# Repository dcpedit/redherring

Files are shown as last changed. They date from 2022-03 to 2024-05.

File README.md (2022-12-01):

# Red Herring Keyboard

Red Herring is a 75% ortholinear keyboard with staggered columns and a split ergonomic layout similar to an Arisu/Alice.  Here you will find the KiCad 6 files for the PCB and plate, along with Illustrator files for the case and wrist rest. Keyboard features:
- Through-hole or hotswap socket variants
- Diodes arranged in a unique herringbone pattern
- Large rotary encoder knob (up to 48mm diameter)
- 64x128 OLED display (SSD1107)
- Compatible with most standard keycap sets (1.75u for left shift, and 2u for left space)
- Different [layout options](http://www.keyboard-layout-editor.com/#/gists/cf2afd92ae2ac742f6cb94146715b537), including ISO

## Firmware ([Vial](https://get.vial.today/)):

If you're flashing a brand new MCU, you will need to use an ISP programmer to install a bootloader first. I didn't have an AVR ISP programmer, so I flashed a spare Elite-C to do this.

Look in the `firmware` folder for hex files and more info on flashing.

## Photos:
Red Herring Keyboard - Black top
Red Herring Keyboard - OLED
Red Herring Keyboard - Black bottom
Red Herring - white case and wrist resttop
Red Herring - white case side

## Thanks!
This project would not have been possible without the time and dedication of everyone who worked on the amazing keyboards I learned and took inspiration from.  To name a few: Jabberwocky, Boardrun, Basketweave, Adelheid, Mercutio, Discipline, and Mysterium.

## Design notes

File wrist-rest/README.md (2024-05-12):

# Red Herring Wrist Rest

wrist-rest-wires

This design uses 6 layers cut out of 3mm thick acrylic.  Actual thickness may vary (mine was around 2.8mm).

## Standoffs
This build will require round M2 standoffs with the following lengths:

| |Size|Qty|
|:--|:--:|:--:|
|**Top Row**|M2x10mm|5|
|**Bottom Row**|M2x5mm|5|

## Screws
The following screw sizes are also needed
| |Size|Qty|
|:--|:--:|:--:|
|**Top Layer**|M2x8mm|10|
|**Bottom Layer (upper)**|M2x6mm|5|
|**Bottom Layer (lower)**|M2x5mm|5|

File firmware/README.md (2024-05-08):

# Red Herring Firmware

If you're flashing a brand new MCU, you need to first assemble the PCB, and then flash the ATmega32A with the USBaspLoader bootloader.

[QMK's ISP flashing guide](https://github.com/qmk/qmk_firmware/blob/master/docs/isp_flashing_guide.md)

## Flash Bootloader for the ATMEGA32A

You will need an ISP programmer to flash the Atmega32a chip with the USBaspLoader bootloader, so please refer to the QMK guide on what to use.  I had a spare Elite-C lying around, so I converted that to an ISP programmer using `pro_micro_ISP_B6_10.hex`, which was taken from the QMK guide.  Here's a pic of my makeshift setup.  (I put a small amount of solder on the wire pins and tacked them down onto the pads so that I could easily remove them later)



Wire your ISP programmer up to the PCB header using the diagram below. Then connect your computer to the ISP programmer. The PCB should NOT be connected directly to your computer.

redherring-isp-pins

Install `avrdude` or QMK MSYS for Windows:
- [MacOS avrdude](https://formulae.brew.sh/formula/avrdude)
- [Windows QMK MSYS](https://msys.qmk.fm/)

Use the `bootloader.hex` and flash with the following commands.  You will need to replace `<PORT>` with the location of your ISP's USB port.  You can look in your Device Manager (Windows ex: Ports -> `COM3`), or your `/dev` directory for `tty.usb*` (MacOS ex: `/dev/tty.usbmodem12345`).  You may need to change `avrisp` to the programmer that you're using.  Again, please check the [QMK docs](https://github.com/qmk/qmk_firmware/blob/master/docs/isp_flashing_guide.md) for more info.

### View attached device
```
avrdude -c avrisp -P <PORT> -b 19200 -p atmega32 -v
```

Example output:

avrdude-verbose

### Flash bootloader
```
avrdude -c avrisp -P <PORT> -b 19200 -p atmega32 -U flash:w:bootloader.hex:i
```

Example output:

avrdude-flash

### Set fuses
```
avrdude -c avrisp -P <PORT> -p atmega32 -U lfuse:w:0x1f:m -U hfuse:w:0xc0:m
```

Example output:

avrdude-fuse

You can now disconnect your ISP programmer and connect the PCB directly to your computer via the USB-C port.  Make sure you have [QMK Toolbox](https://github.com/qmk/qmk_toolbox/releases) open so that you can monitor the status window and flash the firmware.  In order to put the board into bootloader mode you must first hold the boot button (labeled BOOT) and while holding the boot button, press the reset button (labeled RESET) and release it. Wait for another second, then release the boot button as well. The microcontroller will now be in bootloader mode if the bootloader is present and prepared correctly.

The QMK Toolbox status window should output: `USBAsp device connected`.

Continue to flash as you normally would from this point (ie. QMK Toolbox using `redherring_vial.hex`). If you have autoflash enabled on QMK Toolbox, it will do it automatically now. Reset the board once more in order to use the new firmware (you can do this by unplugging and replugging it or by pressing and releasing the reset button.)

If you're still having issues with the bootloader, you can also take a look at this detailed guide written by Protieus: [Atmega32a_Flash_Guide.pdf](https://github.com/dcpedit/redherring/blob/main/firmware/Atmega32a_Flash_Guide.pdf)

## VIA Firmware (recommended)

Source:

https://github.com/qmk/qmk_firmware/tree/master/keyboards/dcpedit/redherring

Flash the `redherring_via.hex` file and visit https://usevia.app/ to remap your keys

## Vial Firmware

You'll need the [Vial software](https://get.vial.today) if you want to remap your keys.

Source:

https://github.com/dcpedit/vial-qmk-dev/blob/dcpedit/keyboards/dcpedit/redherring

Use the `redherring_vial.hex` firmware.  Below is a list of commands to build.

```
git clone --recurse-submodules -b dcpedit https://github.com/dcpedit/vial-qmk.git
cd vial-qmk
make git-submodule
make dcpedit/redherring:vial
```

## Change OLED graphic

In order to change the image, you'll first need to create a 64x128 two-tone image using only black and white pixels (no gray) and save it as a PNG.  Once you do that, upload your image to this online image2cpp tool (https://javl.github.io/image2cpp/), and use the below settings.  Note that the output format is "plain bytes" and draw mode is "vertical - 1 bit per pixel"

image2cpp

Clicking the "Generate code" button will produce the code you need.

Next open the `redherring.c` file in `keyboards/dcpedit/redherring/`

Add a define for you image size at the top (assuming 64x128):

```
#define LOGO_SIZE 1024
```

Next define a `render_logo` function.  If one already exists, you can replace that.  This is where you paste in the code generated from image2cpp.  Here's an example of what the function would look like:

```
static void render_logo(void) {
    static const char PROGMEM oled_logo[LOGO_SIZE] = {
        /* Paste the output from image2cpp below */
        0x00, 0x00, 0x00, 0x00, 0x00, 0x00, 0x00, 0x00, 0x00, 0x00, 0x00, 0x00, 0x00, 0x00, 0x00, 0x00,
        0x00, 0x00, 0x00, 0x00, 0x00, 0x00, 0x00, 0x00, 0x00, 0x00, 0x00, 0x00, 0x00, 0x00, 0x00, 0x00,
        0x00, 0x00, 0x00, 0x00, 0x00, 0x00, 0x00, 0x00, 0x00, 0x00, 0x00, 0x00, 0x00, 0x00, 0x00, 0x00,
        /* ... should be 64 lines of this ... */
    };

    oled_write_raw_P(oled_logo, LOGO_SIZE);
}
```

Finally, update your `oled_task_kb` function in `redherring.c` to display the logo.  It should look something like this:

```
bool oled_task_kb(void) {
    if (!oled_task_user()) {
        return false;
    }
    render_logo();
    return true;
}
```

You can see an example image in the [example_logo folder](example_logo)

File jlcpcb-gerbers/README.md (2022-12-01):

# Gerber files for JLCPCB

| File | Description | Thickness | Size
| ---- | --- | --- | ----
| `pcb-gerbers.zip`  | Red Herring Through-Hole PCB | 1.6 mm | 364.4 x 167.2 mm
| `pcb-hotswap-gerbers.zip`  | Red Herring Hotswap PCB | 1.6 mm | 364.4 x 167.2 mm
| `solenoid-gerbers.zip` | Red Herring solenoid edition PCB | 1.6 mm | 364.4 x 167.2 mm
| `plate-gerbers.zip` | Red Herring switch plate (1.2mm) | 1.2 mm | 364.4 x 144.6 mm

I've pre-generated these files so that they can be uploaded directly to [JLCPCB](https://jlcpcb.com).  The were generated following [this guide](https://support.jlcpcb.com/article/149-how-to-generate-gerber-and-drill-files-in-kicad) which was written for KiCad 5.  If the website is not able to calculate the dimensions, you can enter them in manually.

For KiCad 6, I used the following settings in case anyone wanted to generate the files themselves

## Plot
KiCad6_Plot

## Generate drill files
KiCad6_Drill

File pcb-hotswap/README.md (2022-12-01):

# Red Herring PCB
#### Hotswap variant by [ungodly.design](https://ungodly.design)
The files here were created with KiCad 6.

KiCad-screenshot

## Manufacturing
I used JLCPCB.com to get this manufactured.  They have [a good tutorial](https://support.jlcpcb.com/article/149-how-to-generate-gerber-and-drill-files-in-kicad) on how to generate the Gerber files from KiCad. If the website is not able to calculate the dimensions, you can enter it in manually.  Here are the details

- Size: 364.4 mm x 167.2 mm
- Thickness: 1.6 mm FR4
- 2 Layers

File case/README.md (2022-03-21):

# Red Herring Stacked Acrylic Case and Foam

case-wires

See the [build guide](/build-guide) for the hardware information and assembly instructions.

The normal case file contains the design for a flat edge case, while the rounded file is the design for rounded edges.  (I've only built the rounded version)

There are a total of 11 layers of 3mm thick acrylic including the feet.  For the top layers that have clear windows, the windows are held in place by friction, so sizing might be a bit tricky.  I also used the natural tappering of the arcylic edges to "lock" the windows in place. It might be possible to use few dabs of acrylic cement (ie. Weld-On #4) to hold it in place, but I have not tried this.

## Acrylic Layer Descriptions

The layers should be cut out of 3mm thick acrylic.  The actual thickness of the acrylic I used was about 2.8mm.

| Layer | Description |
| ----- | --- |
| 11d Top Clear Solenoid | Clear top for solenoid edition
| 11c Top Solenoid Windows | Windows solenoid edition
| 11b Top Alternate Windows | Windows for alternate top
| 11b Top Alternate | Alternate top with windows
| 11 Top Clear | Standard clear top
| 10 Top Layer | Layer #10
| 9 Top Layer | Layer #9
| 8 Layer PCB Top | Layer that goes right above the PCB
| 7 Bottom Spacer | Layer #7
| 6 Bottom Spacer | Layer #6
| 5 Bottom | Keyboard bottom
| Feet 4 | Layer #4 (largest foot layer)
| Feet 3 | Layer #3
| Feet 2 | Layer #2
| Feet 1 | Layer #1 (smallest foot layer)

You do not need to cut all the #11 layers.  What you need will depend on which case you're building.  Follow this guide below.

### Case: clear top
- 11 Top Clear

### Case: matching color top with clear windows
- 11b Top Alternate
- 11b Top Alternate Windows

### Case - Solenoid edition: clear top
- 11d Top Clear Solenoid

### Case - Solenoid edition: matching color top with clear windows 
- 11b Top Alternate
- 11c Top Solenoid Windows

**Notes:** I had to cut a small hole in the window for the solenoid because it was too tall to fit inside the case without it.  The windows are secured in place by friction only, so the sizing is important.  I adjusted the kerf for my laser cutter, so your mileage may vary.  If the fitment is too loose, it may just fall out, but I think a few dabs of acrylic cement around the perimeter of the window may hold it in place.  If you're unsure about the window fitment, I'd suggest going with the all-clear top to be safe.

There's also a spacer file which I used to cut a ~0.5mm spacer to go in between the PCB and solenoid (for the solenoid edition).  This was helpful for a few reasons: it dapens the sounds, it allows me to use the screws I had, which would've been too long otherwise, and it prevents the solenoid piston from hitting the boot button.  The spacer doesn't have to be exact. I cut mine out of a cracker box.  Cutting one out with scissors and punching small holes for the screws will work just fine as well.

## Foam Layer Descriptions

The plate foam (between switch plate and PCB) should be 2mm thick, and the bottom foam (under the PCB) should be 1mm thick.  There's not that much room inside the case, so going too thick may cause the case the bulge.  To thin, and the PCB might shift around a bit, but probably not noticeable.  I used EVA foam, which works really well with laser cutters.

| Layer | Description |
| ----- | --- |
| Plate Foam | 2mm foam (between switch plate and PCB)
| Bottom Foam A | 1mm foam (underneath PCB)

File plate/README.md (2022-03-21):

red herring plate

# Red Herring switch plate
The files here were created with KiCad 6.

## Manufacturing
I used JLCPCB.com to get this manufactured.  They have [a good tutorial](https://support.jlcpcb.com/article/149-how-to-generate-gerber-and-drill-files-in-kicad) on how to generate the Gerber files from KiCad. If the website is not able to calculate the dimensions, you can enter it in manually.  Here are the details

- Size: 144.5 mm x 364.4 mm
- Thickness: 1.2 mm FR4 (I found that going under 1.5 mm made it easier for the switches to snap in)

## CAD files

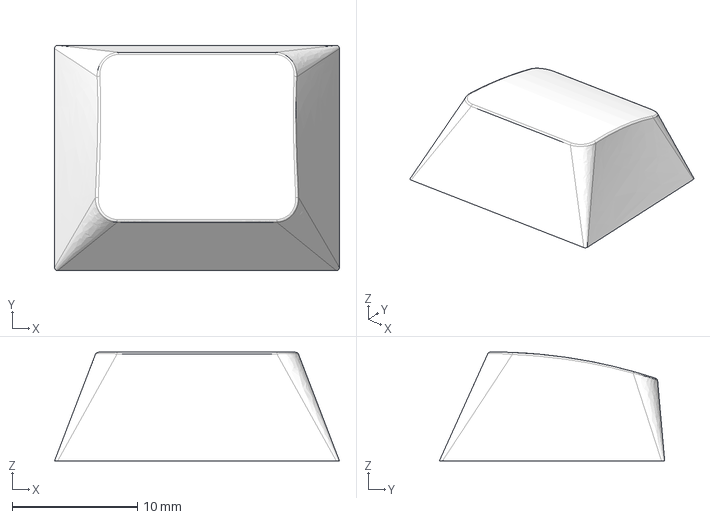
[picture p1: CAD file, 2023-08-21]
pcb-hotswap/1.25u.step
22.8 x 18.0 x 8.70 mm

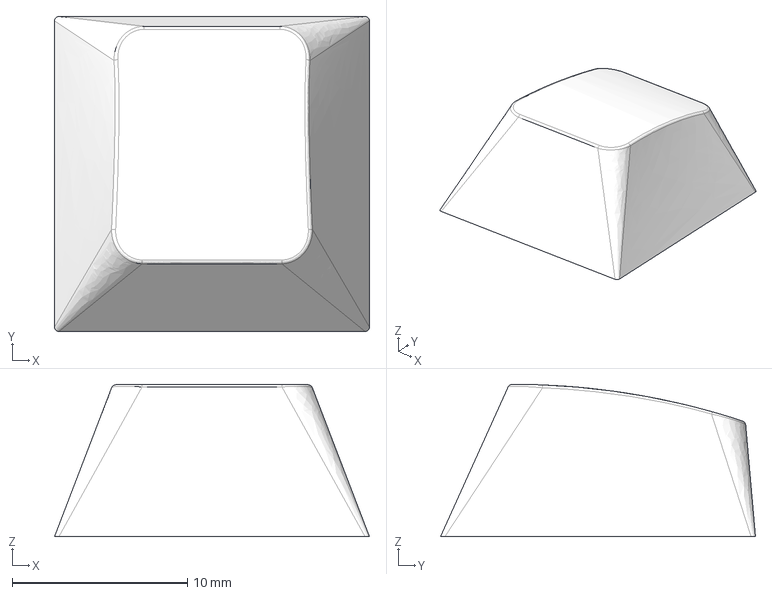
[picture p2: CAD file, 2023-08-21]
pcb-hotswap/1UMX.step
18.0 x 18.0 x 8.70 mm

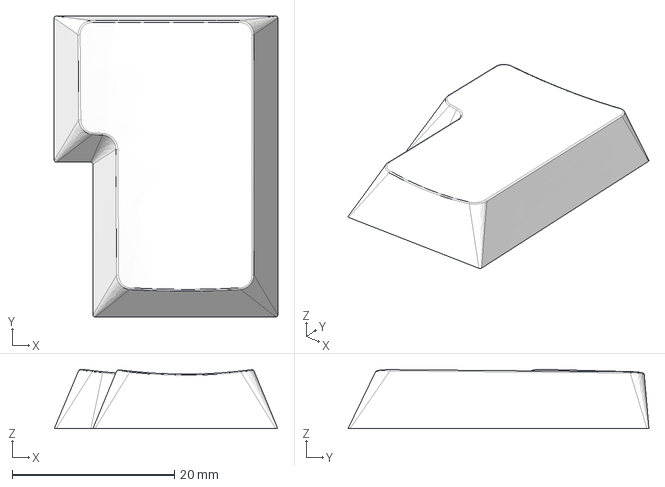
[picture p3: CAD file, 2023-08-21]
pcb-hotswap/ISO-ENTER.step
27.5 x 37.0 x 7.30 mm

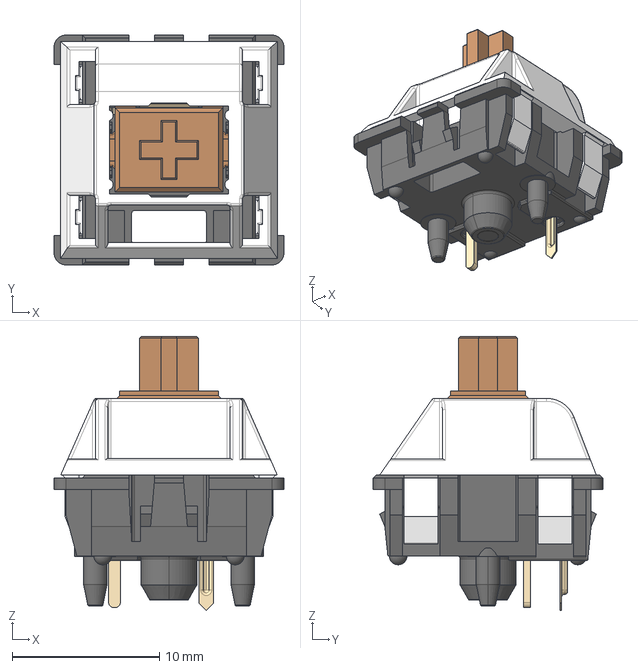
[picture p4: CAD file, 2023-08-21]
pcb-hotswap/SW_Cherry_MX_PCB.stp
15.6 x 15.6 x 18.6 mm

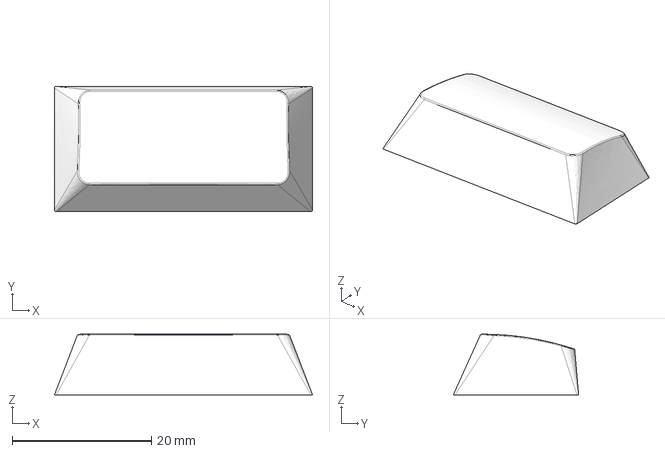
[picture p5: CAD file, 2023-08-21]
pcb-hotswap/2.25MX.step
37.1 x 18.0 x 8.70 mm

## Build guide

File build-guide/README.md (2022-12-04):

# Build Guide
This guide is based off the Basketweave guide by null-ll.  The components are layed out in a similar fashion.

## Required Components
You will need the following tools and components to build the keyboard (not included in the kit):
- Soldering iron and solder
- Flush side cutters
- No-clean flux
- 5 PCB mount 2u stabilizers
- USB Type C cable
- 1.5mm allen wrentch (black screws, knob screw)
- 1.27mm allen wrentch (silver screws)

## Components
| Ref | Component | Qty | Notes |
| --- | --- | --- | ----- |
| C1, C2  | 22pF Capacitor | 2 | [Link](https://www.mouser.com/ProductDetail/81-RCE5C2A220J0A2H3B)
| C3, C4  | 0.1uF Capacitor | 2 | [Link](https://www.mouser.com/ProductDetail/81-RDER71H104K0M1H3A)
| C5 | 4.7uF Capacitor | 1 | [Link](https://www.mouser.com/ProductDetail/Nichicon/UMT1H4R7MDD?qs=jeFazJX0ZRzElcQ8UcwUoQ%3D%3D)
| D1-92 | 1n4148 Diode | 92  | [Link](https://www.mouser.com/ProductDetail/512-1N4148TR)
| D93, D94| 3.6V Zener Diode | 2 | [Link](https://www.mouser.com/ProductDetail/78-TZX3V6A)
| FUSE | 500mA Resettable fuse  | 1 | [Link](https://www.mouser.com/ProductDetail/652-MFR050)
| ISP | 6 pin header | 1 | [Link](https://www.mouser.com/ProductDetail/649-1012938190601BLF)
| OLED | 4 pin header | 1 | [Link](https://www.mouser.com/ProductDetail/517-929850-01-04-RA)
| USB | GCT USB4085 USB C port | 1 | [Link](https://www.digikey.com/short/249pdt21), [Link](https://mou.sr/3Dgb4TO)
| POWER | 3mm LED | 1 | [Link](https://www.mouser.com/ProductDetail/859-LTL-4222)
| Capslock| 1.8mm LED (3mm rev 2)  | 1
| R1, R7  | 1.5k Resistor | 2 | [Link](https://www.mouser.com/ProductDetail/603-MFR-12FTF52-1K5)
| R8 | 470 Resistor | 1 | [Link](https://www.mouser.com/ProductDetail/603-CFR-12JT-52-470R)
| R2, R5  | 5.1k Resistor | 2 | [Link](https://www.mouser.com/ProductDetail/603-MFR-12FTF52-5K1)
| R3, R4  | 75 Resistor | 2 | [Link](https://www.mouser.com/ProductDetail/603-CFR-12JR-52-75R)
| R6 | 10k Resistor | 1 | [Link](https://www.mouser.com/ProductDetail/YAGEO/MFR-12FTF52-10K?qs=oAGoVhmvjhzLlUYKKBtdYQ%3D%3D), [Link](https://mou.sr/3xgqcNf)
| U1 | ATmega32A | 1 | [Link](https://www.digikey.com/short/2d8502n2), [Link](https://mou.sr/3RYkSGt)
| | 40 pin IC socket | 1 | [Link](https://www.mouser.com/ProductDetail/571-1-2199299-5)
| RESET, BOOT | 6mm push button | 2 | [Link](https://www.mouser.com/ProductDetail/642-MJTP1230A)
| Y1 | 16MHz Crystal | 1 | [Link](https://www.mouser.com/ProductDetail/520-ECS160-18-4X-CKM)
| | 0.96in 64x128 OLED | 1 | [Link](https://www.aliexpress.us/item/3256801406424682.html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)
| | EC11 Rotary encoder | 1 | [Link](https://www.digikey.com/short/90v3w37p), [Link](https://mou.sr/3QyXFcA)
| | 48mm Knob | 1 | [Link](https://www.aliexpress.com/item/4001316125393.html?spm=a2g0o.order_list.0.0.21ef1802wSwYcm)
| | M2 24mm standoff | 5 | Upper edge, [Link](https://www.aliexpress.com/item/32968906213.html?spm=a2g0o.order_list.0.0.21ef1802wSwYcm)
| | M2 18mm standoff | 1 | Middle left
| | M2 15mm standoff | 1 | Middle right
| | M2 13mm standoff | 5 | Lower edge
| | M2 6mm screw | 12  | Bottom, [Link](https://www.aliexpress.com/item/4001072025844.html?spm=a2g0o.order_list.0.0.21ef1802wSwYcm), [Link](https://www.aliexpress.com/item/1005002357962115.html?spm=a2g0o.order_list.0.0.21ef1802wSwYcm)
| | M2 8mm screw | 12  | Top
| | Rubber Feet | 4 | [Link](https://smile.amazon.com/gp/product/B088T7XMCY/ref=ppx_yo_dt_b_search_asin_title?ie=UTF8&th=1)
| | Red Herring PCB | 1
| | Switch plate | 1
| | Plate foam (2mm) | 1
| | Case foam (1mm) | 1
| | Acrylic case layers | 7

## Standoff Positions
||Left | | | |Right|
|:--|:--:|:--:|:--:|:--:|:--:|
|**Top** |24mm|24mm|24mm|24mm|24mm|
|**Middle**|18mm| | | |15mm|
|**Bottom**|13mm|13mm|13mm|13mm|13mm|

## Instructions
Some things to keep in mind is that there's very little clearance under the PCB, which is why the bottom foam is only 1mm.  Make sure you keep things low-profile by clipping pins flush with the solder joints, and/or folding then down flat against the PCB before soldering whenever possible.

One general tip is to bend the legs of the diodes/resistors/capacitors/LEDs outward after insterting them into the holes so that they stay in place when the PCB is flipped over.  This also reduces the height of the protruding legs, espeically if you also clip them flush with the solder joints.

### USB Port
I like doing the USB port first because I get lots of space to work with.  Heat resistant tape will be useful here to keep the usb port in place.
Solder one of the large legs first and check that the port is flat against the PCB and not crooked before soldering the other three legs. \
Solder the smaller pins by applying no-clean flux across the pins, then drag a small amount of solder across the pins until all the holes are filled.  If you accidentally bridge some pins, just clean all the solder off your solding iron tip, and try to "pick up" the extra solder with it.  If that doesn't work, you can use solder wick.

usbc

### Zener Diodes (D93, D94)
**This part has specific orientation** - black line on the diode lines up with the square pad (right side).

d93-d94

### Resistors (R1-7)
Orientation does not matter. Solder based on the labeled values.
| Ref | Value |
| --- | ----- |
| R1, R7 | 1.5k  |
| R2, R5 | 5.1k  |
| R3, R4 | 75 |
| R6 | 10k |

r7-r1
r5-r2
r3-r4
r6

### Capslock LED (optional)
Check your switch before doing this.  You may need to solder the LED **after** you solder the switch, especially if the switch does not have a large opening on the bottom for the LED.  Short leg \
goes in the square pad.  Use the left holes for a stepped keycap.

caps-led

### Capslock 470 resistor (R8)
Orientation does not matter.

r8

#### Rev 2 Capslock
The resistor and LED for rev 2 was moved up to the top of the PCB above the MCU, so look for the labels there.  The kit may come with a 470Ω resistor, but you can test the brightness before soldering.  I've found that with white colored LEDs, a higher resistance was needed to make it less bright (ie. 10kΩ)

caps_lock_r2

### Capacitors (C1-4)
Orientation does not matter. Solder based on the labeled values.
| Ref | Value |
| --- | ----- |
| C1, C2 | 22pF  |
| C3, C4 | 0.1uF |

c1
c2
c3
c4

### Capacitor (C5)
**This part has a specific orientation** - longer leg goes in square pad (white mark on the capacitor points up)

c5

### Fuse
Orientation does not matter. Fold down after soldering.

fuse

### Crystal (Y1)
Orientation does not matter.

y1

### Power LED
**This part has a specific orientation** - shorter leg and flat side of the LED line up with the square pad

power

### Push Button (RESET, BOOT) and IC Socket
Push buttons have no specific orientation. \
Align the notch on the IC Socket with the markings on the PCB. Fold the pins inward against the PCB before soldering.

reset-boot
mcu-socket

### ISP Pin Header
Orientation does not matter, but the longer pins go on top so that you can solder the shorter bottom pins.

isp1

### OLED Header
There's only about 10mm of space between the PCB and the top window.  I had to file my header down to about 7mm in height (basically right when the metal connectors started to show through, which you can see in the picture below).  I also removed the plastic spacer from the pins on the OLED so that it was just the 4 bare pins, which I had to clip down so that the OLED would sit flush against the shorter header.  (Tip: clip the pins at an angle so that they're easier to insert into the header).  After inserting it into the header, and making sure that there's no gaps, the total height from the top of the OLED pins (highest point) to the bottom of the header was just a tad over 9mm.

Once you're confident that you won't have any clearance issues, insert the OLED display into the header.  This is important because you want to align the display to look perfectly vertical and parallel to the PCB.  With the display firmly seated into the header, insert the header pins into the holes on the PCB.  Using as little solder as possible, tack down only **one** pin so that it holds the display in place.  Look straight down onto the display screen and make sure that it's vertical.  Now tilt the PCB onto its side and make sure the display is parallel to the PCB.  If it looks off in any way, heat the solder up again and make minor adjustments while the solder is still molten.  Then hold it in place until the solder solidifies.  Once the position of the display looks correct, solder the **other** pins that don't have solder yet, and then finally, the pin that had a minimal amount of solder.

oled-header

### ATmega32A
Insert ATmega32A into the IC socket. Make sure the notch on the microcontroller aligns with the notch in the IC socket and the markings on the PCB.

### 1n1418 Diodes (D1-D92)
**This part has a specific orientation** - black line on the diode lines up with the square pad (points up)

d1-d44
d45-d92

###  Encoder
Install the stabilizers, then place the plate on top. \
Fold the pins inward against the PCB before soldering.

rotary-encoder

### PCB Mount Stabalizers (x5)
This is also a high resolution image of the completed PCB.

full_board

### Plate Foam & Switch plate

The 2mm plate foam goes between the PCB and switch plate.  Make sure those are in place before placing your switches in.  As you insert switch one at a time, make sure they snap into switch plate completely.  You man need to wedge a finger or tool in between the PCB and plate to push the plate upwards while pushing the switch downwards.

IMG_3048 (1)

## Case Assembly
Double check that the protective paper masking has been peeled off the front **and** back of eacy acrylic layer.  Try to find a dust-free area to work in, and have a microfiber cloth handy to wipe of dust that collects on the acrylic.  Best to keep the masking on until needed to minimize dust and scratches.

### Feet #1 - 6mm screws (x5) & 24mm standoffs (x5)



### Feet #2



### Feet #2 - 6mm screw & 18mm standoff



### Feet #4 - 6mm screw & 15mm standoff



### Bottom - 6mm screws (x5) & 13mm standoffs (x5)



### Spacer #1



### 1mm Foam



### Spacer #2



### Assembled PCB with stabalizers, 2mm plate foam, switch plate, & switches
Make sure your OLED display has been inserted into the OLED header. 2mm plate foam goes inbetween the PCB and switch plate.



### PCB top layer
The acrylic areas that extend inward on this layer need to fit into the open areas in the switch plate.  The fitment is tight in order to keep the PCB from shifting, so make sure this layer is pushed all the way down with no gaps and that it's not caught onto an edged of the switch plate.  The PCB basically sits on top of the 1mm foam, and is held in position by the 2mm foam and this acrylic layer.



### Top layer #1



### Top layer #2



### Clear top: 8mm screws (x12)



#### Rev 2 top with Windows
This revision uses a top layer that matches the rest of the case, but with cutouts for clear acrylic pieces over the top components and OLED screen.  The windows are held in place by the natural taper of the acrylic edges, so it's easiest to insert/remove the pieces from the bottom.  I've found that the easiest way is to place the clear windows down first, and then placing the top layer down while shifting the window pieces into position before finally pressing everything into place.

RH_v3_windows

### Rotary Knob
You may need to tighten the knob screws (one one each side) slightly before the knob hits the bottom.  Otherwise, you may not have engough clearance below the knob for the rotary knob "button" to be depressed (when you push straight down on the knob).



### Rubber feet

Peel paper off the adhesive rubber feet and place one on each corner of the bottom of the keyboard.

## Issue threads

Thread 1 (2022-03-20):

About solenoid

F1hone, 2022-03-20:
Hello,
It's a really interesting keyboard, it's a really nice piece of work, I'm especially interested in his solenoids, "da da da", sounds great, but the best I can find on my local shopping site The parameters of the solenoid valve are DC3V 0.5A; DC5V (0.83A, 0.41A), I want to know which one should I choose, I am looking forward to your answer, thank you

dcpedit, 2022-03-20:
I would go with the 3v one just to be safe. The 5v one might work depending on how much power your other components are drawing. Hard to predict without actually trying it out.

F1hone, 2022-03-21:
Thank you very much for your answer,
I will give it a try and I will come back and let you know when I get the results

jhc2414169248, 2022-04-06:
>
Hi, did you try successfully? Solenoid with 5V working?

dcpedit, 2022-04-06:
I was not able to get a 5V solenoid working.  Only a 4.5V worked for me, so I would not go higher than that.

F1hone, 2022-04-08:
Sorry, I'm not allowed to receive courier due to the novel coronavirus epidemic in my area, so I haven't tried it yet, but I think 3v should work

dcpedit, 2022-04-27:
I've received confirmation that a 3v solenoid works.

Closed 2022-04-27.

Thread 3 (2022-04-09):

Can't flash redherring_vial.hex [could not find USB device ]

DAydDaY, 2022-04-09:
Hello, I have a problem when I flashing the vial firmware. What should I do, please? These are the qmk tookbox output:
```
*** USBasp device disconnected (WinUSB): Van Ooijen Technische Informatica USBasp (16C0:05DC:0102)
*** AVRISP device connected (usbser): Microsoft USB 串行设备 (COM38) (16C0:0483:0100) [COM38]
*** USBasp device connected (WinUSB): Van Ooijen Technische Informatica USBasp (16C0:05DC:0102)
*** USBasp device connected (WinUSB): Van Ooijen Technische Informatica USBasp (16C0:05DC:0102)
*** Attempting to flash, please don't remove device
>>> avrdude.exe -p atmega32a -c avrisp -U flash:w:"D:\Program Files\avrdude-v7.0-rc1-windows-x64\redherring_vial.hex":i -P COM38

    avrdude.exe: AVR device initialized and ready to accept instructions

    Reading | ################################################## | 100% 0.01s

    avrdude.exe: Device signature = 0x000001
    avrdude.exe: Expected signature for ATmega32A is 1E 95 02
                 Double check chip, or use -F to override this check.

    avrdude.exe done.  Thank you.
*** Flash complete

>>> avrdude.exe -p atmega32a -c usbasp -U flash:w:"D:\Program Files\avrdude-v7.0-rc1-windows-x64\redherring_vial.hex":i
    avrdude.exe: error: could not find USB device with vid=0x16c0 pid=0x5dc vendor='www.fischl.de' product='USBasp'

*** Flash complete
    avrdude.exe done.  Thank you.
```

dcpedit, 2022-04-27:
My guess is that you're using the incorrect COM port.  When you go into your Windows Device Manager, what do you see listed in the Serial port section?

DAydDaY, 2022-04-27:
Thanks for your reply! I have solved this problem with using MSYS to flash the hex. But I still can't flash hex with toolbox... Also I tried the 3V solenoid and it works very well👏

Closed 2022-04-27.

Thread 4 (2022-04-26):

redherring_vial.hex (solenoid support) source files

baconspoon85, 2022-04-26:
Would it be possible for you to commit the source files for redherring_vial.hex? The one with solenoid support that you most recently committed in this repository? I would like to edit the keymap to support tap-mod shift keys on the spacebars, but vial doesn't support that function, so I’d have to compile new firmware. I found some files you posted at https://github.com/dcpedit/vial-qmk/tree/dcpedit/keyboards/dcpedit/redherring, but I suspect those don’t correspond to the published hex. I recompiled it to test this theory by cloning the found files to qmk_firmware/keyboards/redherring and running 'make redherring:vial' in QMK MSYS. I was able to compile a new hex and flash it to the board, but there are three distinct differences in function:

1. OLED font and logo are no longer displaying (I just get garbled noise).
2. Rotary encoder won't control volume or page up/down as expected.
3. Vial no longer recognizes the keyboard.

Everything else works fine but I'm hoping with the right source files I can avoid loosing those functions.

baconspoon85, 2022-04-27:
Never mind. I just realized the tap-hold keycodes are in the Quantum tab and QMK Settings has Tapping Term under the Tap-Hold tab. Would still be cool to be able to update the firmware directly though. I'd like to try getting a track nub to work on one of these.

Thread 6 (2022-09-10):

OLED BOM header part verification request

JellyTitan, 2022-09-10:
The 4 pin OLED header link in the bom points to a part that looks different than the part used in the build guide.
Does the BOM link point to the correct part? If not, can you point me to the correct part?
[Mouse part](https://www.mouser.com/ProductDetail/517-929850-01-04-RA)
[Build guide image](https://user-images.githubusercontent.com/800930/144702052-e8cfc8cd-1268-4091-b99a-a7bb67b7605b.jpg)

baconspoon85, 2022-09-11:
That's a stock image on the Mouser site. They do that a lot to represent a family of product rather than put an image for each iteration. If you read the description, it's for single row, 4-position connector like it should be.

JellyTitan, 2022-09-11:
Thank you! I appreciate your patience - I learned something new.

Closed 2022-09-11.

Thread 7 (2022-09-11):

Can you recommend an alternate 10k resistor?

JellyTitan, 2022-09-11:
10k resistor in BOM has long lead times at both Mouser and digi-key. Can you recommend an alternative?
[BOM 10k resistor](https://www.mouser.com/ProductDetail/603-MFR-12FTF52-10K)
I _think_ this might be a viable replacement, but I'm not sure about the whole carbon vs metal and the different % bit.
[Possible alternative](https://www.mouser.com/ProductDetail/YAGEO/CFR-12JT-52-10K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)

dcpedit, 2022-09-11:
Yes, that alternative should work fine

JellyTitan, 2022-09-11:
Thanks! I appreciate the quick response  - I'll submit a PR with an alternative link.

Closed 2022-09-11.

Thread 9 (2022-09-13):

Hotswap support for Mill-Max socket

saikocat, 2022-09-13:
It seems like the current PCB mounting hole diameter is only 1.47mm, which I think make it near impossible to insert the Mill-Max hotswap socket due to the same thickness without accounting for drilling tolerance/error.

Like for example the 0305 has the follow specs:
* Diameter: 1.47 mm
* Recommended PCB mounting hole diameter: 1.50-1.55 mm
* Flange thickness: 0.64 mm
* Flange diameter: 1.93 mm

EDIT: Is the reason due to the switch being raised higher (than sitting flushed) causing issue with the acrylic layers?

Is there any plan to support this? Or strictly pure soldered board only? Thanks!

dcpedit, 2022-09-13:
The current design actually does support mill-max sockets.  I've built a
few boards with them and sockets drop right into the hole with no issue.
As you can see in this photo, the bottom pcb has the sockets installed:
https://imgur.com/8ku5P5I

On Tue, Sep 13, 2022 at 3:03 AM Duc Hoa, Nguyen ***@***.***>
wrote:

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

saikocat, 2022-09-14:
Thank you for the reply. I've experienced that 1.5mm to be snug-fit, in rare cases failure to push through. I guess this is highly depending on the PCB manufacturer tolerance.

The specs https://www.mill-max.com/products/receptacle/0305 also suggests the mounting hole to a bit larger (though its diameter is exactly the same as your footprint hole at 1.47mm).

This could be a confirmation bias thing from our experiences. But if it works for majority of the people building the board then we can just close this issue.

JellyTitan, 2022-10-02:
The 0305's worked for me on boards made by jlcpcb. Perhaps these should be added to BOM as optional?

dcpedit, 2022-12-01:
PR #11 which adds hotswap sockets to the PCB has been merged.

Closed 2022-12-01.

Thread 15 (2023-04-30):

When I put in the OLED screen, my keyboard fails to be recognized.

Vlastier, 2023-04-30:
so yeah, when I put in the OLED screen for my board, it fails to recognize it in windows, but if I don't solder it in, it is getting recognized. I wonder if people can help me out here, as I really want an OLED screen working

dcpedit, 2023-05-03:
The only thing I can think of is that your system is not giving the keyboard enough power, so when the OLED screen is installed, the extra power draw essentially disables your keyboard.  Some things I'd recommend trying:

- Use a shorter USB cable
- Use a higher quality/name brand USB cable
- Use a powered USB hub
- Try testing on another computer that can provide more power to the USB port

Vlastier, 2023-05-16:
Okay, so I tried doing all of these but my problem right now is that after typing for around 15 seconds the keyboard disconnects. Do you have any idea with where it happens? this also happens when I don't connect the OLED.

baconspoon85, 2023-05-16:
It sounds like your issue may just be the quality of the USB connection. It doesn't always have to be the cable, and I'm assuming based on your comments that you tried several cables. Does it disconnect and reconnect? The port itself can be easily damaged during soldering. Also, improper soldering can result in cold solder joints that are intermittent. I don't mean to condecend either. If you are confident in your solder work, then never mind. Otherwise, maybe post pictures? Does the USB connection feel tight? Does intentionally wiggling the cable cause disconnections or reconnect the board after its been disconnected from typing?

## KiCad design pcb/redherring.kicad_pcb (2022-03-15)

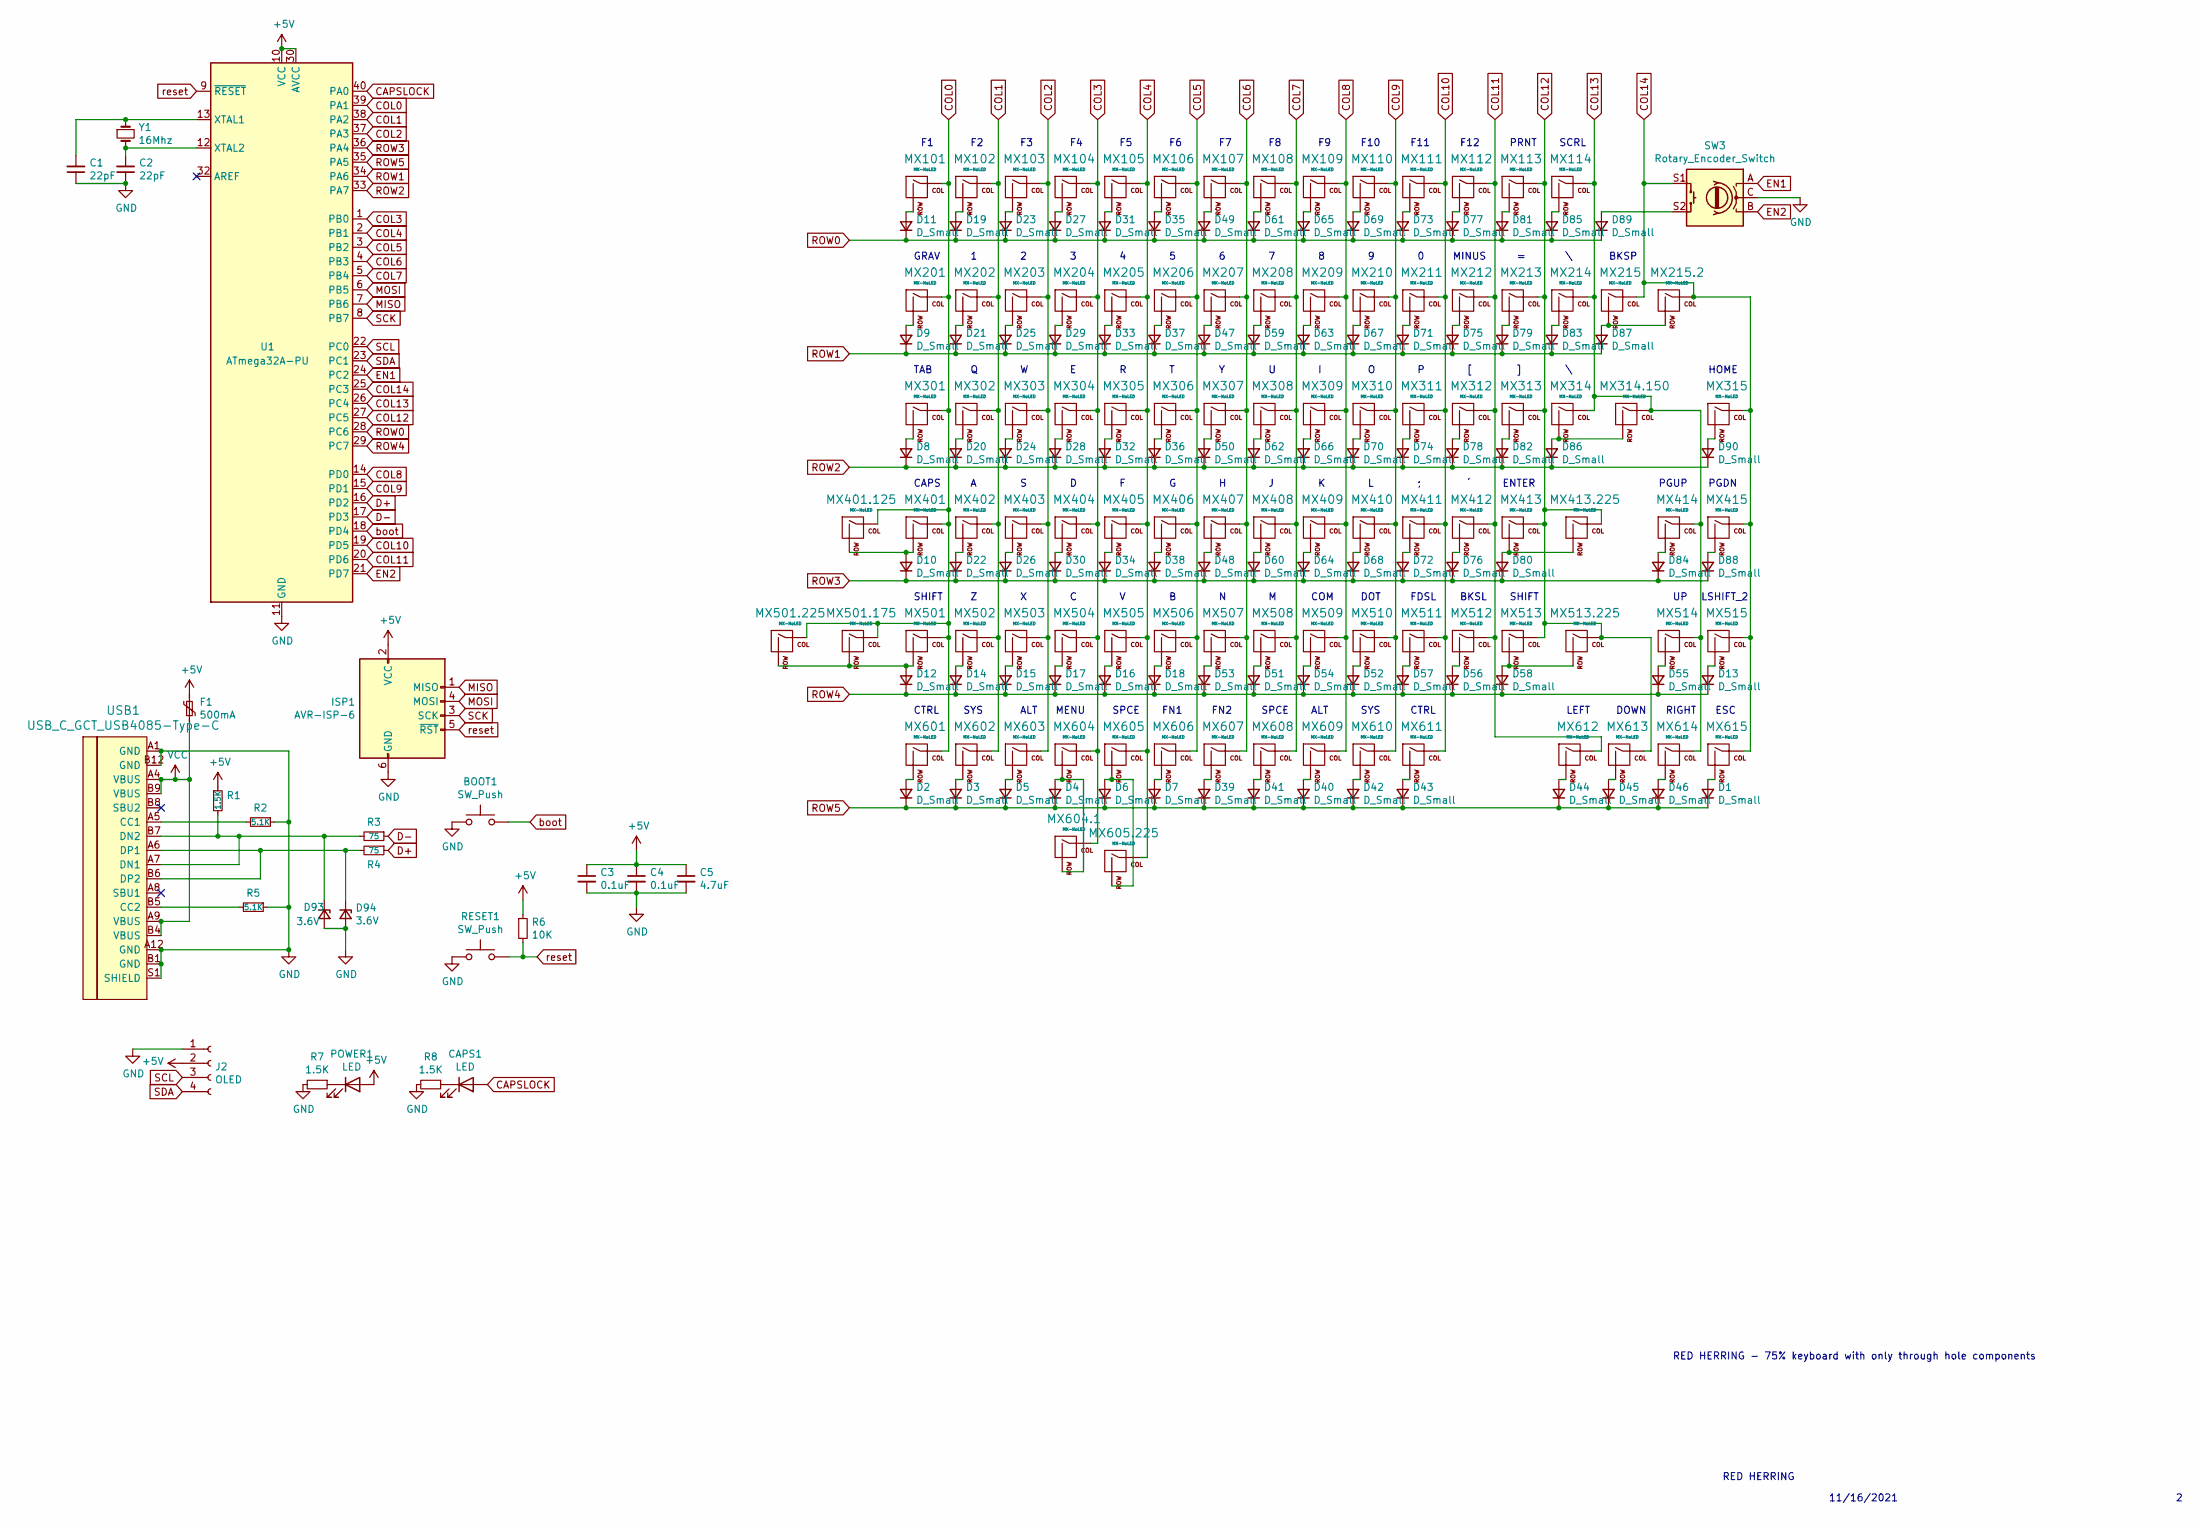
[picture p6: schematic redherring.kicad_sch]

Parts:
BOOT1: SW_Push; SW_PUSH_6mm
C1, C2: 22pF; C_Disc_D3.0mm_W2.0mm_P2.50mm
C3, C4: 0.1uF; C_Disc_D4.3mm_W1.9mm_P5.00mm
C5: 4.7uF; CP_Radial_D4.0mm_P1.50mm
CAPS1: LED; LED_D3.0mm_Clear
D1, D2, D3, D4, D5, D6, D7, D8, D9, D10, D11, D12, D13, D14, D15, D16, D17, D18, D19, D20, D21, D22, D23, D24, D25, D26, D27, D28, D29, D30, D31, D32, D33, D34, D35, D36, D37, D38, D39, D40, D41, D42, D43, D44, D45, D46, D47, D48, D49, D50, D51, D52, D53, D54, D55, D56, D57, D58, D59, D60, D61, D62, D63, D64, D65, D66, D67, D68, D69, D70, D71, D72, D73, D74, D75, D76, D77, D78, D79, D80, D81, D82, D83, D84, D85, D86, D87, D88, D89, D90: D_Small; D_DO-35_SOD27_P5.08mm_Horizontal
D93, D94: 3.6V; D_DO-35_SOD27_P7.62mm_Horizontal
F1: 500mA; polyfuse_5.1mm
ISP1: AVR-ISP-6; PinHeader_2x03_P2.54mm_Vertical
J2: OLED; SSD1306_OLED
MX101, MX102, MX103, MX104, MX105, MX106, MX107, MX108, MX109, MX110, MX111, MX112, MX113, MX114, MX201, MX202, MX203, MX204, MX205, MX206, MX207, MX208, MX209, MX210, MX211, MX212, MX213, MX214, MX215, MX302, MX303, MX304, MX305, MX306, MX307, MX308, MX309, MX310, MX311, MX312, MX313, MX314, MX315, MX402, MX403, MX404, MX405, MX406, MX407, MX408, MX409, MX410, MX411, MX412, MX414, MX415, MX501, MX502, MX503, MX504, MX505, MX506, MX507, MX508, MX509, MX510, MX511, MX512, MX514, MX515, MX604.1, MX606, MX607, MX612, MX613, MX614, MX615: MX-NoLED; MXOnly-1U-NoLED
MX215.2: MX-NoLED; MXOnly-2U-NoLED
MX301, MX314.150: MX-NoLED; MXOnly-1.5U-NoLED
MX401, MX501.175: MX-NoLED; MXOnly-1.75U-NoLED
MX401.125, MX513, MX601, MX602, MX603, MX604, MX609, MX610, MX611: MX-NoLED; MXOnly-1.25U-NoLED
MX413: MX-NoLED; MXOnly-ISO-ROTATED-ReversedStabilizers-NoLED
MX413.225, MX501.225, MX513.225: MX-NoLED; MXOnly-2.25U-NoLED
MX605: MX-NoLED; MXOnly-2U-ReversedStabilizers-NoLED
MX605.225: MX-NoLED; MXOnly-2.25U-ReversedStabilizers-NoLED
MX608: MX-NoLED; MXOnly-2.75U-ReversedStabilizers-NoLED
POWER1: LED; LED_D3.0mm_Clear
R1, R7, R8: 1.5K; R_Axial_DIN0204_L3.6mm_D1.6mm_P5.08mm_Horizontal
R2, R5: 5.1K; R_Axial_DIN0204_L3.6mm_D1.6mm_P5.08mm_Horizontal
R3, R4: 75; R_Axial_DIN0204_L3.6mm_D1.6mm_P5.08mm_Horizontal
R6: 10K; R_Axial_DIN0204_L3.6mm_D1.6mm_P5.08mm_Horizontal
RESET1: SW_Push; SW_PUSH_6mm
SW3: Rotary_Encoder_Switch; RotaryEncoder_Alps_EC11E-Switch_Vertical_H20mm
U1: ATmega32A-PU; DIP-40_W15.24mm
USB1: USB_C_GCT_USB4085-Type-C; USB_C_GCT_USB4085
Y1: 16Mhz; Crystal_HC49-4H_Vertical

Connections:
+5V: C3.1, C4.1, C5.1, F1.1, ISP1.2 (VCC), J2.2, POWER1.2 (A), R1.1, R6.1, U1.10 (VCC), U1.30 (AVCC); also elsewhere on the board
CAPSLOCK: CAPS1.2 (A), U1.40 (PA0); also elsewhere on the board
COL0: MX101.1 (COL), MX201.1 (COL), MX301.1 (COL), MX401.1 (COL), MX401.125.1 (COL), MX501.1 (COL), MX501.175.1 (COL), MX501.225.1 (COL), MX601.1 (COL), U1.39 (PA1)
COL1: MX102.1 (COL), MX202.1 (COL), MX302.1 (COL), MX402.1 (COL), MX502.1 (COL), MX602.1 (COL), U1.38 (PA2)
COL2: MX103.1 (COL), MX203.1 (COL), MX303.1 (COL), MX403.1 (COL), MX503.1 (COL), MX603.1 (COL), U1.37 (PA3)
COL3: MX104.1 (COL), MX204.1 (COL), MX304.1 (COL), MX404.1 (COL), MX504.1 (COL), MX604.1 (COL), MX604.1.1 (COL), U1.1 (PB0)
COL4: MX105.1 (COL), MX205.1 (COL), MX305.1 (COL), MX405.1 (COL), MX505.1 (COL), MX605.1 (COL), MX605.225.1 (COL), U1.2 (PB1)
COL5: MX106.1 (COL), MX206.1 (COL), MX306.1 (COL), MX406.1 (COL), MX506.1 (COL), MX606.1 (COL), U1.3 (PB2)
COL6: MX107.1 (COL), MX207.1 (COL), MX307.1 (COL), MX407.1 (COL), MX507.1 (COL), MX607.1 (COL), U1.4 (PB3)
COL7: MX108.1 (COL), MX208.1 (COL), MX308.1 (COL), MX408.1 (COL), MX508.1 (COL), MX608.1 (COL), U1.5 (PB4)
COL8: MX109.1 (COL), MX209.1 (COL), MX309.1 (COL), MX409.1 (COL), MX509.1 (COL), MX609.1 (COL), U1.14 (PD0)
COL9: MX110.1 (COL), MX210.1 (COL), MX310.1 (COL), MX410.1 (COL), MX510.1 (COL), MX610.1 (COL), U1.15 (PD1)
COL10: MX111.1 (COL), MX211.1 (COL), MX311.1 (COL), MX411.1 (COL), MX511.1 (COL), MX611.1 (COL), U1.19 (PD5)
COL11: MX112.1 (COL), MX212.1 (COL), MX312.1 (COL), MX412.1 (COL), MX512.1 (COL), MX612.1 (COL), U1.20 (PD6)
COL12: MX113.1 (COL), MX213.1 (COL), MX313.1 (COL), MX413.1 (COL), MX413.225.1 (COL), MX513.1 (COL), MX513.225.1 (COL), MX613.1 (COL), U1.27 (PC5)
COL13: MX114.1 (COL), MX214.1 (COL), MX314.1 (COL), MX314.150.1 (COL), MX414.1 (COL), MX514.1 (COL), MX614.1 (COL), U1.26 (PC4)
COL14: MX215.1 (COL), MX215.2.1 (COL), MX315.1 (COL), MX415.1 (COL), MX515.1 (COL), MX615.1 (COL), SW3.S1, U1.25 (PC3)
D+: R4.1, U1.16 (PD2)
D-: R3.1, U1.17 (PD3)
EN1: SW3.A, U1.24 (PC2)
EN2: SW3.B, U1.21 (PD7)
GND: BOOT1.1, C1.1, C2.1, C3.2, C4.2, C5.2, D93.2 (A), D94.2 (A), ISP1.6 (GND), J2.1, R2.1, R5.1, R7.2, R8.2, RESET1.1, SW3.C, U1.11 (GND), U1.31 (GND), USB1.A1 (GND), USB1.A12 (GND), USB1.B1 (GND), USB1.B12 (GND), USB1.S1 (SHIELD); also elsewhere on the board
MISO: ISP1.1 (MISO), U1.7 (PB6)
MOSI: ISP1.4 (MOSI), U1.6 (PB5)
unnamed: C1.2, U1.13 (XTAL1), Y1.1
unnamed: C2.2, U1.12 (XTAL2), Y1.2
unnamed 26: CAPS1.1 (K), R8.1; also elsewhere on the board
unnamed: D1.2 (A), MX615.2 (ROW)
unnamed: D2.2 (A), MX601.2 (ROW)
unnamed: D3.2 (A), MX602.2 (ROW)
unnamed: D4.2 (A), MX604.2 (ROW), MX604.1.2 (ROW)
unnamed: D5.2 (A), MX603.2 (ROW)
unnamed: D6.2 (A), MX605.2 (ROW), MX605.225.2 (ROW)
unnamed: D7.2 (A), MX606.2 (ROW)
unnamed: D8.2 (A), MX301.2 (ROW)
unnamed: D9.2 (A), MX201.2 (ROW)
unnamed: D10.2 (A), MX401.2 (ROW), MX401.125.2 (ROW)
unnamed: D11.2 (A), MX101.2 (ROW)
unnamed: D12.2 (A), MX501.2 (ROW), MX501.175.2 (ROW), MX501.225.2 (ROW)
unnamed: D13.2 (A), MX515.2 (ROW)
unnamed: D14.2 (A), MX502.2 (ROW)
unnamed: D15.2 (A), MX503.2 (ROW)
unnamed: D16.2 (A), MX505.2 (ROW)
unnamed: D17.2 (A), MX504.2 (ROW)
unnamed: D18.2 (A), MX506.2 (ROW)
unnamed: D19.2 (A), MX102.2 (ROW)
unnamed: D20.2 (A), MX302.2 (ROW)
unnamed: D21.2 (A), MX202.2 (ROW)
unnamed: D22.2 (A), MX402.2 (ROW)
unnamed: D23.2 (A), MX103.2 (ROW)
unnamed: D24.2 (A), MX303.2 (ROW)
unnamed: D25.2 (A), MX203.2 (ROW)
unnamed: D26.2 (A), MX403.2 (ROW)
unnamed: D27.2 (A), MX104.2 (ROW)
unnamed: D28.2 (A), MX304.2 (ROW)
unnamed: D29.2 (A), MX204.2 (ROW)
unnamed: D30.2 (A), MX404.2 (ROW)
unnamed: D31.2 (A), MX105.2 (ROW)
unnamed: D32.2 (A), MX305.2 (ROW)
unnamed: D33.2 (A), MX205.2 (ROW)
unnamed: D34.2 (A), MX405.2 (ROW)
unnamed: D35.2 (A), MX106.2 (ROW)
unnamed: D36.2 (A), MX306.2 (ROW)
unnamed: D37.2 (A), MX206.2 (ROW)
unnamed: D38.2 (A), MX406.2 (ROW)
unnamed: D39.2 (A), MX607.2 (ROW)
unnamed: D40.2 (A), MX609.2 (ROW)
unnamed: D41.2 (A), MX608.2 (ROW)
unnamed: D42.2 (A), MX610.2 (ROW)
unnamed: D43.2 (A), MX611.2 (ROW)
unnamed: D44.2 (A), MX612.2 (ROW)
unnamed: D45.2 (A), MX613.2 (ROW)
unnamed: D46.2 (A), MX614.2 (ROW)
unnamed: D47.2 (A), MX207.2 (ROW)
unnamed: D48.2 (A), MX407.2 (ROW)
unnamed: D49.2 (A), MX107.2 (ROW)
unnamed: D50.2 (A), MX307.2 (ROW)
unnamed: D51.2 (A), MX508.2 (ROW)
unnamed: D52.2 (A), MX510.2 (ROW)
unnamed: D53.2 (A), MX507.2 (ROW)
unnamed: D54.2 (A), MX509.2 (ROW)
unnamed: D55.2 (A), MX514.2 (ROW)
unnamed: D56.2 (A), MX512.2 (ROW)
unnamed: D57.2 (A), MX511.2 (ROW)
unnamed: D58.2 (A), MX513.2 (ROW), MX513.225.2 (ROW)
unnamed: D59.2 (A), MX208.2 (ROW)
unnamed: D60.2 (A), MX408.2 (ROW)
unnamed: D61.2 (A), MX108.2 (ROW)
unnamed: D62.2 (A), MX308.2 (ROW)
unnamed: D63.2 (A), MX209.2 (ROW)
unnamed: D64.2 (A), MX409.2 (ROW)
unnamed: D65.2 (A), MX109.2 (ROW)
unnamed: D66.2 (A), MX309.2 (ROW)
unnamed: D67.2 (A), MX210.2 (ROW)
unnamed: D68.2 (A), MX410.2 (ROW)
unnamed: D69.2 (A), MX110.2 (ROW)
unnamed: D70.2 (A), MX310.2 (ROW)
unnamed: D71.2 (A), MX211.2 (ROW)
unnamed: D72.2 (A), MX411.2 (ROW)
unnamed: D73.2 (A), MX111.2 (ROW)
unnamed: D74.2 (A), MX311.2 (ROW)
unnamed: D75.2 (A), MX212.2 (ROW)
unnamed: D76.2 (A), MX412.2 (ROW)
unnamed: D77.2 (A), MX112.2 (ROW)
unnamed: D78.2 (A), MX312.2 (ROW)
unnamed: D79.2 (A), MX213.2 (ROW)
unnamed: D80.2 (A), MX413.2 (ROW), MX413.225.2 (ROW)
unnamed: D81.2 (A), MX113.2 (ROW)
unnamed: D82.2 (A), MX313.2 (ROW)
unnamed: D83.2 (A), MX214.2 (ROW)
unnamed: D84.2 (A), MX414.2 (ROW)
unnamed: D85.2 (A), MX114.2 (ROW)
unnamed: D86.2 (A), MX314.2 (ROW), MX314.150.2 (ROW)
unnamed: D87.2 (A), MX215.2 (ROW), MX215.2.2 (ROW)
unnamed: D88.2 (A), MX415.2 (ROW)
unnamed: D89.2 (A), SW3.S2
unnamed: D90.2 (A), MX315.2 (ROW)
unnamed 117: D93.1 (K), R1.2, R3.2, USB1.A7 (DN1), USB1.B7 (DN2); also elsewhere on the board
unnamed 118: D94.1 (K), R4.2, USB1.A6 (DP1), USB1.B6 (DP2); also elsewhere on the board
unnamed 119: POWER1.1 (K), R7.1; also elsewhere on the board
unnamed 120: R2.2, USB1.A5 (CC1); also elsewhere on the board
unnamed 121: R5.2, USB1.B5 (CC2); also elsewhere on the board
ROW0: D11.1 (K), D19.1 (K), D23.1 (K), D27.1 (K), D31.1 (K), D35.1 (K), D49.1 (K), D61.1 (K), D65.1 (K), D69.1 (K), D73.1 (K), D77.1 (K), D81.1 (K), D85.1 (K), D89.1 (K), U1.28 (PC6)
ROW1: D9.1 (K), D21.1 (K), D25.1 (K), D29.1 (K), D33.1 (K), D37.1 (K), D47.1 (K), D59.1 (K), D63.1 (K), D67.1 (K), D71.1 (K), D75.1 (K), D79.1 (K), D83.1 (K), D87.1 (K), U1.34 (PA6)
ROW2: D8.1 (K), D20.1 (K), D24.1 (K), D28.1 (K), D32.1 (K), D36.1 (K), D50.1 (K), D62.1 (K), D66.1 (K), D70.1 (K), D74.1 (K), D78.1 (K), D82.1 (K), D86.1 (K), D90.1 (K), U1.33 (PA7)
ROW3: D10.1 (K), D22.1 (K), D26.1 (K), D30.1 (K), D34.1 (K), D38.1 (K), D48.1 (K), D60.1 (K), D64.1 (K), D68.1 (K), D72.1 (K), D76.1 (K), D80.1 (K), D84.1 (K), D88.1 (K), U1.36 (PA4)
ROW4: D12.1 (K), D13.1 (K), D14.1 (K), D15.1 (K), D16.1 (K), D17.1 (K), D18.1 (K), D51.1 (K), D52.1 (K), D53.1 (K), D54.1 (K), D55.1 (K), D56.1 (K), D57.1 (K), D58.1 (K), U1.29 (PC7)
ROW5: D1.1 (K), D2.1 (K), D3.1 (K), D4.1 (K), D5.1 (K), D6.1 (K), D7.1 (K), D39.1 (K), D40.1 (K), D41.1 (K), D42.1 (K), D43.1 (K), D44.1 (K), D45.1 (K), D46.1 (K), U1.35 (PA5)
SCK: ISP1.3 (SCK), U1.8 (PB7)
SCL: J2.3, U1.22 (PC0)
SDA: J2.4, U1.23 (PC1)
VCC: F1.2, USB1.A4 (VBUS), USB1.A9 (VBUS), USB1.B4 (VBUS), USB1.B9 (VBUS); also elsewhere on the board
boot: BOOT1.2, U1.18 (PD4); also elsewhere on the board
reset: ISP1.5 (~RST), R6.2, RESET1.2, U1.9 (~RESET); also elsewhere on the board

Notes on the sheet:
FN1
FDSL
SPCE
LEFT
LSHIFT_2
HOME
RED HERRING - 75% keyboard with only through hole components
PRNT
SYS
FN2
PGUP
MENU
SCRL
F10
F11
TAB
COM
PGDN
RIGHT
ESC
11/16/2021
DOWN
SHIFT
DOT
BKSP
ENTER
BKSL
ALT
RED HERRING
CAPS
GRAV
CTRL
F12
MINUS

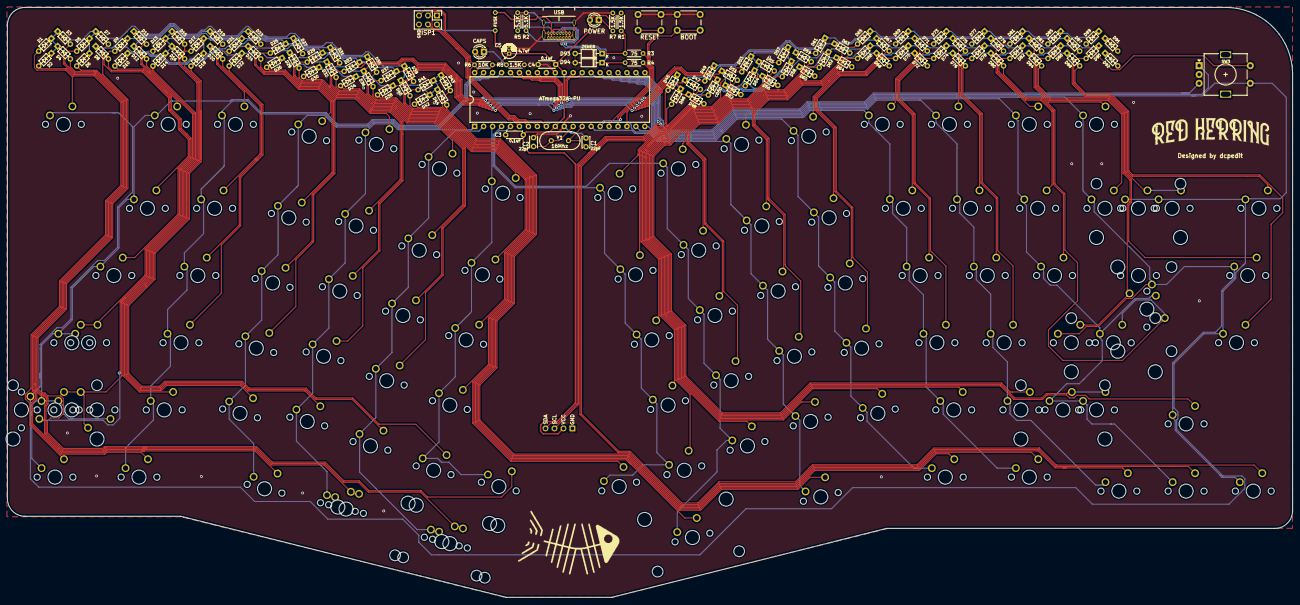
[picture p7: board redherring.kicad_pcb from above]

Board: 2 copper layers, 364.4 x 167.2 mm, 216 parts (0 on the bottom side), 134 nets.

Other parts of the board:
BOOT: SW_Push; SW_PUSH_6mm
CAPS: LED; LED_D3.0mm_Clear
D91, D92: D_Small; D_DO-35_SOD27_P5.08mm_Horizontal
POWER: LED; LED_D3.0mm_Clear
RESET: SW_Push; SW_PUSH_6mm
USB: USB_C_GCT_USB4085-Type-C; USB_C_GCT_USB4085

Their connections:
+5V: POWER.2; also elsewhere on the board
CAPSLOCK: CAPS.2; also elsewhere on the board
GND: BOOT.1, RESET.1, USB.A1, USB.A12, USB.B1, USB.B12, USB.S1; also elsewhere on the board
unnamed 26: CAPS.1; also elsewhere on the board
unnamed 117: USB.A7, USB.B7; also elsewhere on the board
unnamed 118: USB.A6, USB.B6; also elsewhere on the board
unnamed 119: POWER.1; also elsewhere on the board
unnamed 120: USB.A5; also elsewhere on the board
unnamed 121: USB.B5; also elsewhere on the board
VCC: USB.A4, USB.A9, USB.B4, USB.B9; also elsewhere on the board
boot: BOOT.2; also elsewhere on the board
reset: RESET.2; also elsewhere on the board

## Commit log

2022-03-17 Add readme for case
2022-03-18 Add solenoid edition top
2022-03-21 Add pcb details, case stickers
2022-03-21 Add info to case
2022-03-21 Add clear top for solenoid edition
2022-03-25 Generate gerber files
2022-04-16 firmware with solenoid support
2022-05-15 fix screw info
2022-09-10 Updated OLED link on BOM
    Old oled link was dead, replaced with a new link. (Product selected is arbitrary it was a top search result). Tracking code was removed from the URL. Added OLED Resolution to the BOM title.
2022-09-10 Added EC11 Alternate link
    Digikey has the preferred EC11 rotary encoder on back order. Mouser has them in stock, so I added a mouser link.
2022-09-11 Added 10k Resistor alternate link
    Preferred 10k resistor has a long lead time. Alternative link added.
2022-10-30 Add hotswap pcb variant
    Changed through-hole mx switch footprints to hotswap. Re-routed PCB and validated against Design Rules Checker.
    [redherring.kicad_sch, redherring.sch]
2022-12-01 Update readme now that manufactured hotswap pcb has been tested.
2022-12-04 Add more specificity to the oled in the bill of materials.
2023-08-15 Add 3d models and update ISO enter to also be hotswap
    [1.25u.step, 1UMX.step, 2.25MX.step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]
2023-08-17 Update with corrected placement and ISO Enter hotswap. Update plate - WIP
    [redherring-plate.kicad_pcb]
2023-10-12 Fix plate foam
